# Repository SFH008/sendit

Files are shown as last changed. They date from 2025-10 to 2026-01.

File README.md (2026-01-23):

# SendIt — Open Hardware ADC Multitool

SendIt is an open-hardware, open-firmware controller designed as a multi use tool for handling various inputs with a focus on DIY marine usage.  It runs on the Yarrboard Framework and provides a clean web UI for configuration, and multiple different APIs for accessing your data.

Built on the **ESP32-S3**, SendIt has 8 channels of 16-bit ADC with 5 different types of configurable input circuits.  With this board, each channel can be individually configured to handle these types of inputs:

* **4-20ma Transducers/Senders:** sender between +VE and GND
* **Positive Switching:** 0-32v, voltage divider acts as pulldown when NC, switch between SIGNAL and +VE
* **Negative Switching:** 1k ohm, top half of voltage divider acts as pullup, switch between SIGNAL and GND
* **0-32v:** simple voltage divider, voltage wired to SIGNAL
* **0-10k ohm:** voltage divider, external resistor wired from SIGNAL to GND
* **0-5v:** simple voltage divider, voltage wired to SIGNAL
* **Thermistor:** 0-10k ohm, wired as normal
* **Raw/Passthrough:** no extra circuitry - wire your own custom circuit

# Hardware

## Controller Board

### Core capabilities:

- ESP32-S3 module with WiFi and USB-C  
- 12–30 V DC input with onboard power regulation  
- Can be powered by USB C or external power input
- 8 x 16-bit ADC channels with 5 selectable circuits
- Selectable sensor VCC voltage for each channel (3.3v, 5v, 24v, external power)
- 30mA resettable fuse on sensor VCC
- I²C expansion (QWIIC connector)
- Unused I/O broken out as 2.54mm pin headers

### Rev C Pinout

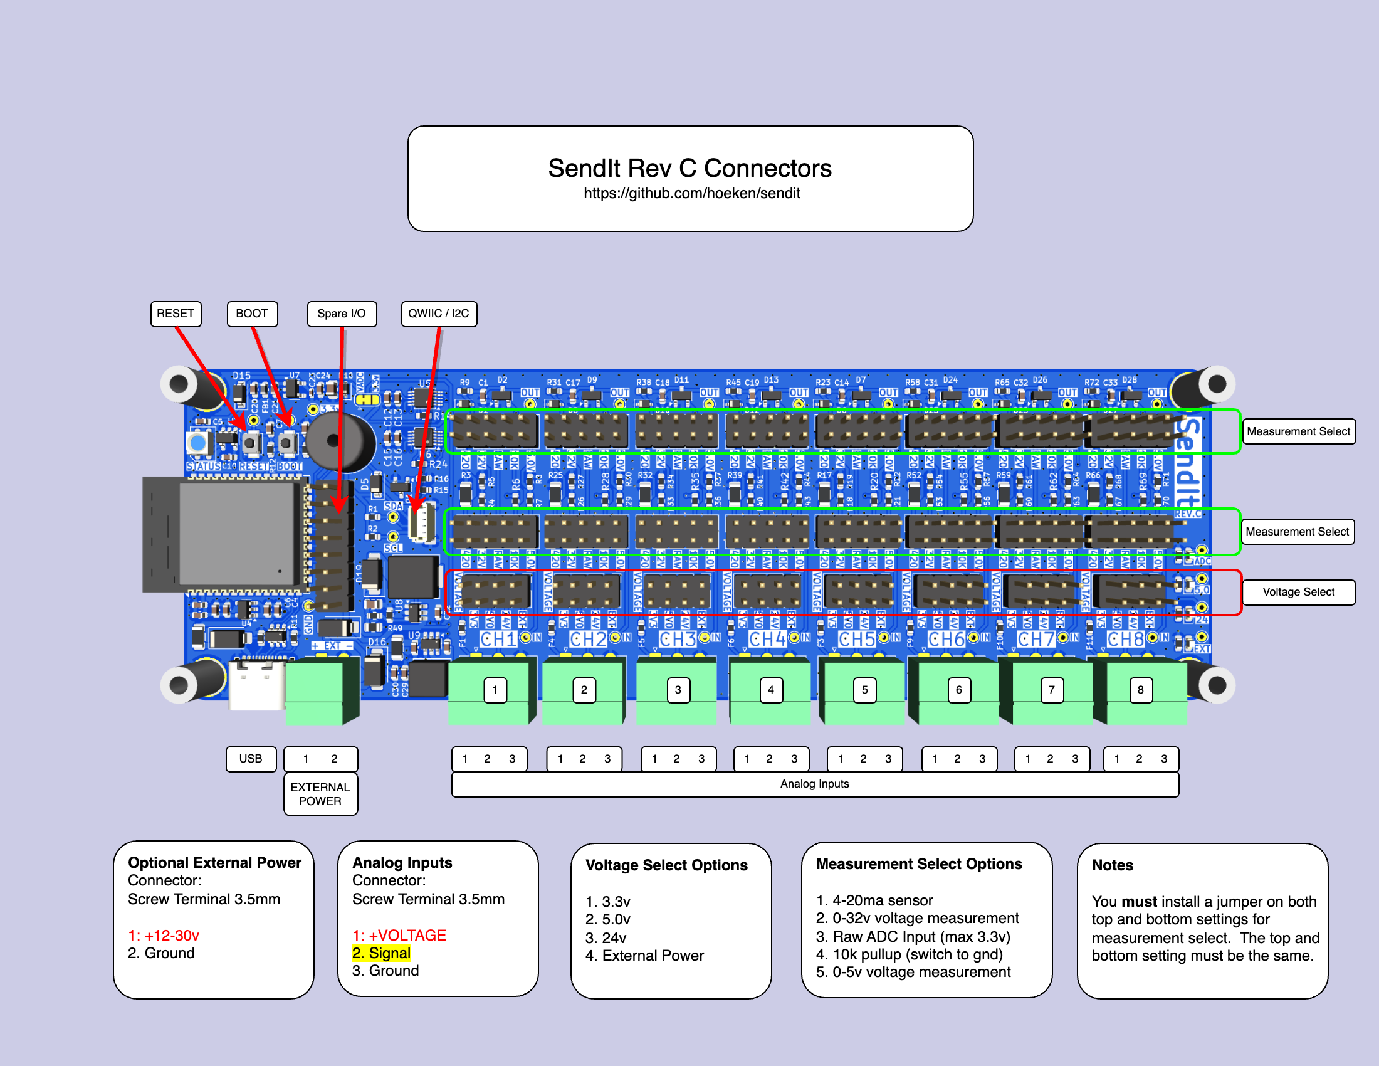
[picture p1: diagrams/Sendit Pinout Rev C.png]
SendIt Rev C Pinout


### ADC Input Channel

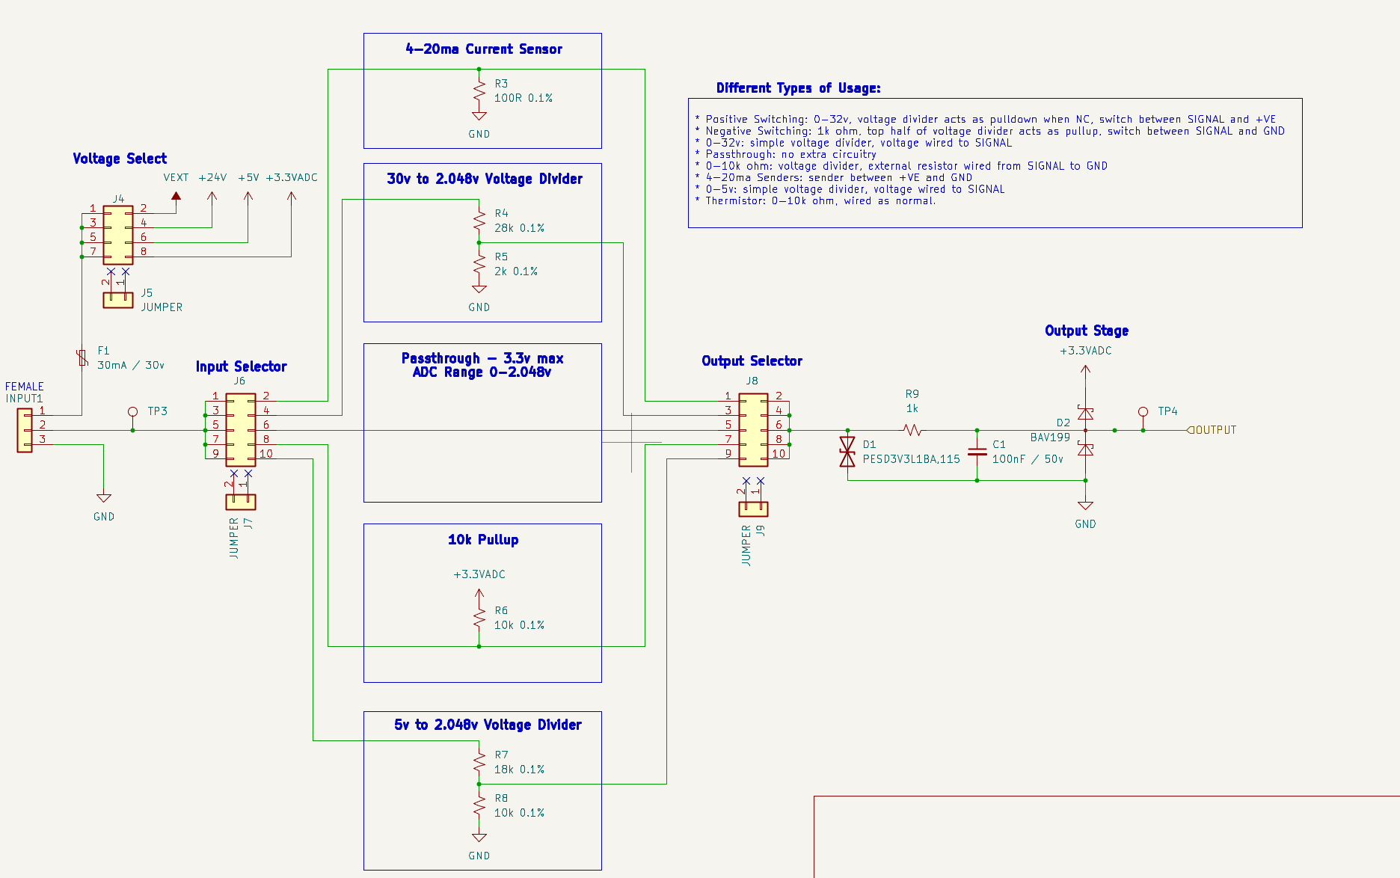
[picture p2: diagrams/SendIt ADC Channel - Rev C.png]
SendIt Rev C ADC Channel


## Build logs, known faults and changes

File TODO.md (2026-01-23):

# Rev D TODO

* lm74700 reverse polarity on VEXT
* remove pesd3.3v on adc line
* 1k -> 4.7k on the adc input line
* pull in the new esp32-s3 schematic w/ bigger ldo
* wrong p/n for leds - change to green
* 5v + 24v leds still way too bright - check resistor values and change.
* add more thermal gnd vias for regulators
* ideal diode ORing setup on 24v->5v output and USB 5v output
  * Wuxi Maxinmicro MX74610SS (external fet)
  * LM74700 (external fet, p/n re-use)
* usb 5v output -> ideal diode.
* bulk cap on 5v
* expansion header -> bottom and change to smt
* change to bigger / higher amperage chip for 5v to 24v
  * TI TPS55340 -> modern, internal, async -> easy peasy <winner>
  * TI TPS40211 -> modern, external, async kinda complicated
  * TI TPS43061 -> synchronous / more complicated
* change to bigger / higher amperage chip for 24v to 5v
  * DIODES AP64350 (3.5A)
  * DIODES AP64200 (2A)
* add bottom test points to important input / outputs
* update all p/ns per bom/ff

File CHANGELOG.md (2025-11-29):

# Changelog

## REV C

### 🔧 ADC & Analog Front-End
- Switched back to **ADS1115** ADC.
- Removed the **ADC VREF circuit** and added a **solder jumper** for VREF selection.
- Standardized all analog scaling to **2.048 V** reference (instead of 3.3 V).
- Added voltage dividers for **30 V** and **5 V** input ranges.
- Set **4–20 mA shunt resistor** to **100 Ω**.
- Added **pull-up resistors** on ADS1115 ALERT pin.

### ⚡ Power & Regulation
- Added a **buck converter** on the EXT port for **12/24 V → 5 V** to power the ESP32.
  - Includes a jumper to **enable/disable EXT-port power**.
  - EXT port may now be used as **power-only**, **reference-only**, or **both**.
- Added **3.3 V ↔ 5.0 V buffer** for WS2818 LED.
- Switched to **green LEDs** for power indication.
- Removed the **USB-to-serial** and **USB hub** for a simplified ESP32-S3 design.

### 🧩 Connectors & I/O
- Added **QWIIC header**.
- Moved pluggable terminal blocks **down 0.5 mm**.
- Removed jumper for EXT power selection.

### 🧪 Test Points
- Added test points for **3.3 V**, **5.0 V**, **24 V**, **GND**, **SDA**, **SCL**, and others.
- Standardized all test points to **1.5×0.7 mm**.

### 🔊 Piezo & Indicators
- Switched to **passive piezo** and added diode (**Huaneng QMB-09B-03**).

### 🧱 Mechanical & Layout
- Changed upper mounting holes to **SMTSO3080CTJ** hardware.
- Switched to **SMT boot/reset buttons**.
- Removed RTC **clock crystal**.
- Switched boost converter to **MT3608B** for 24 V generation.

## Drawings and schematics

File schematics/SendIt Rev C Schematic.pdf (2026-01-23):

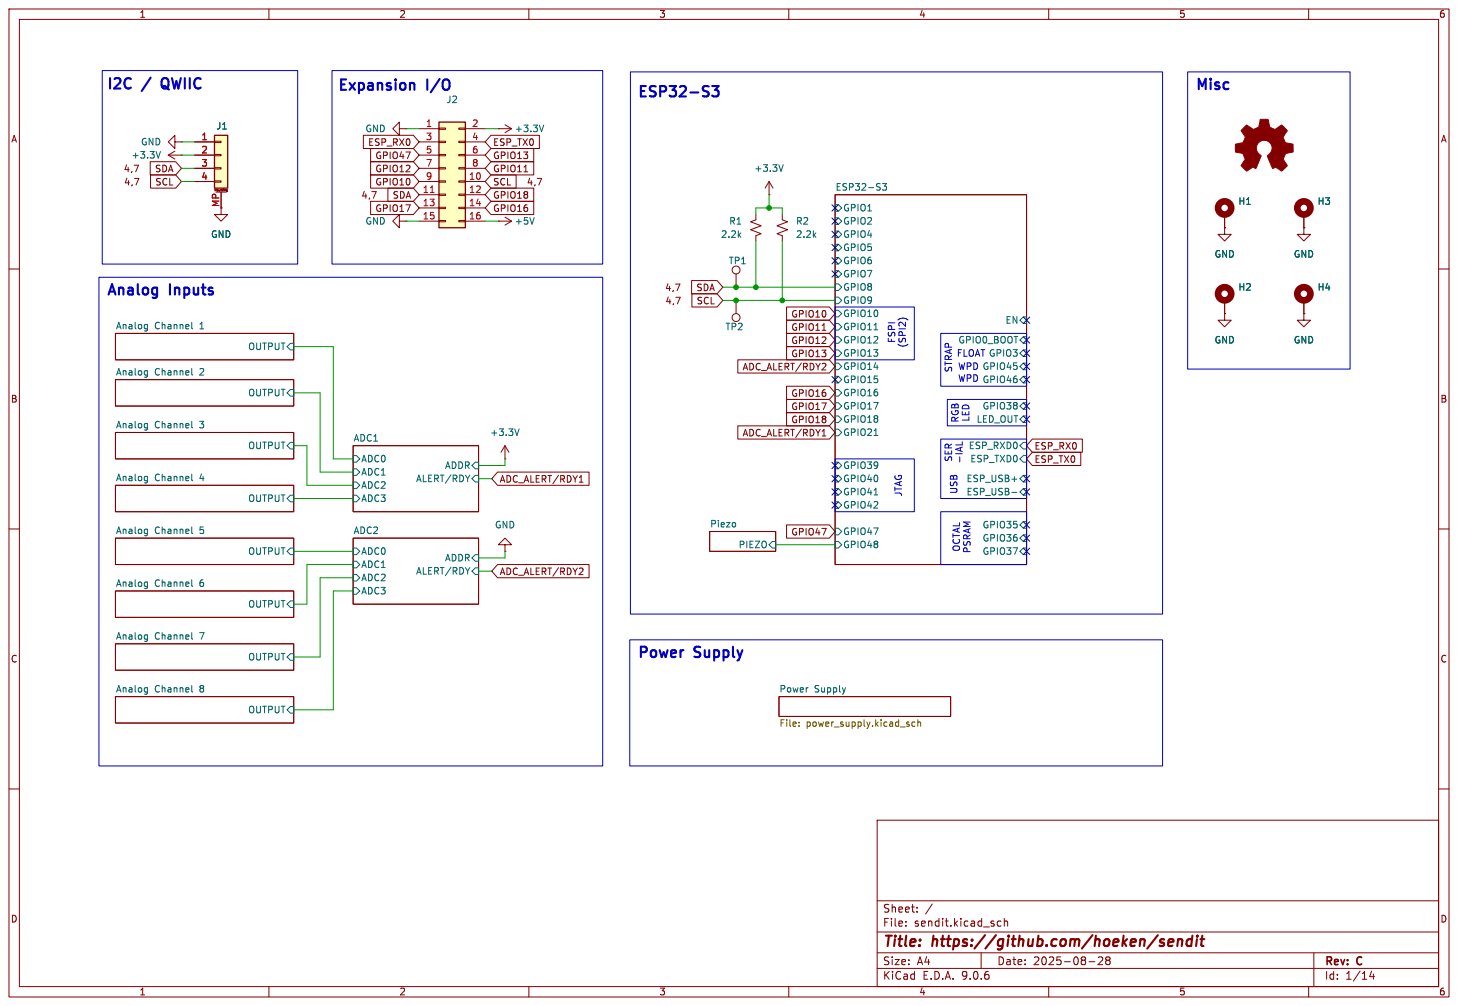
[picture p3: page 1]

Id: 1/14 Title: https://github.com/hoeken/sendit File: sendit.kicad_sch Sheet: /

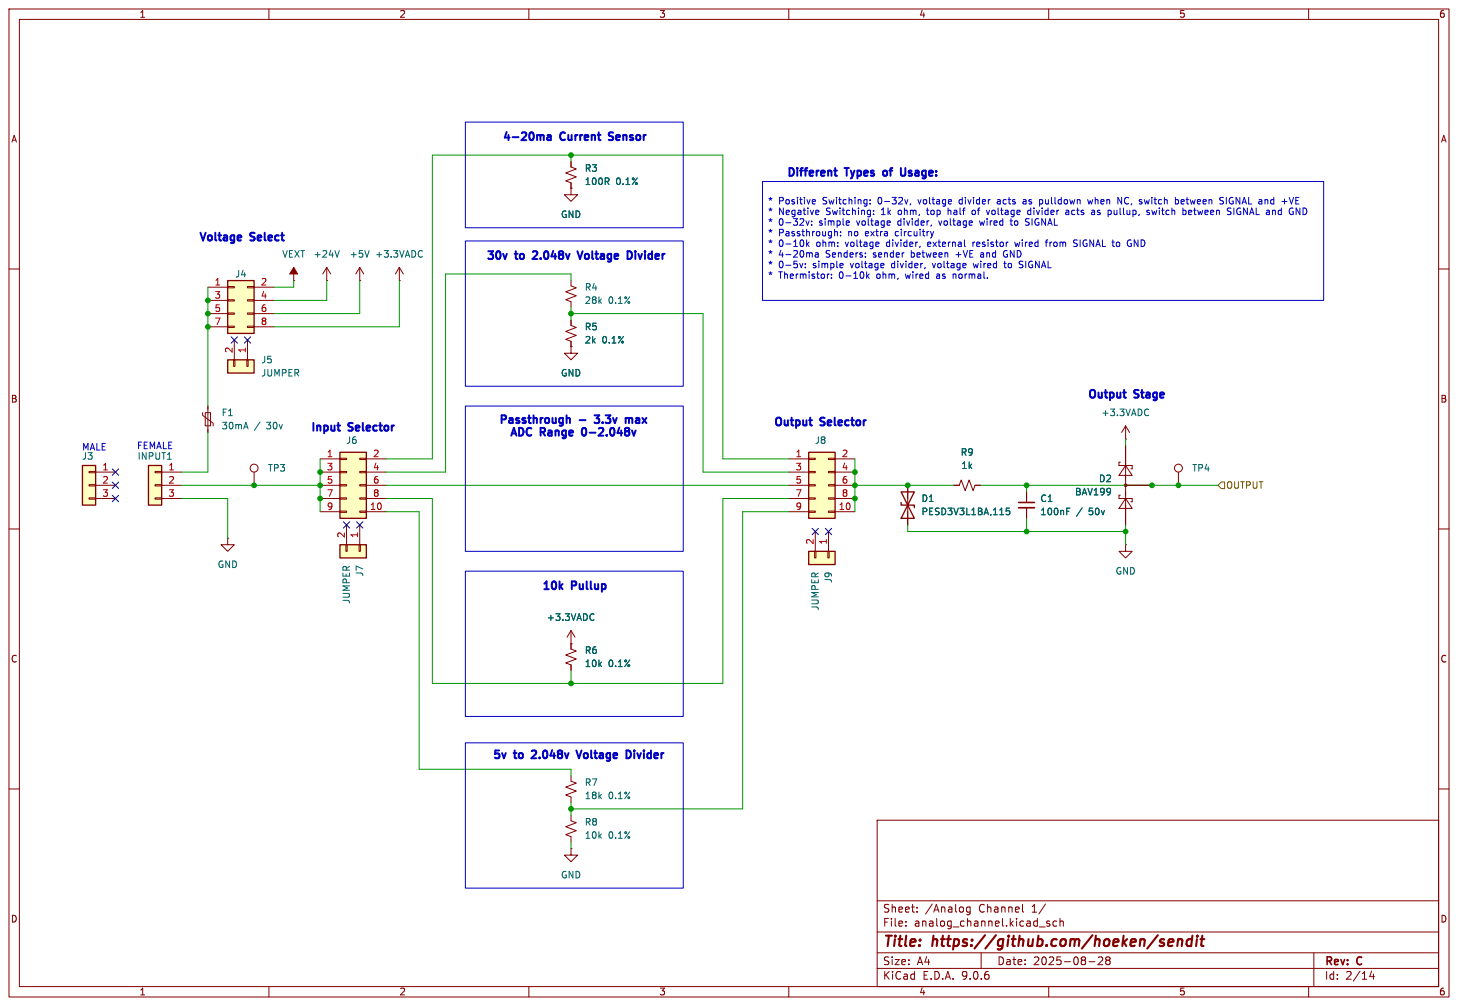
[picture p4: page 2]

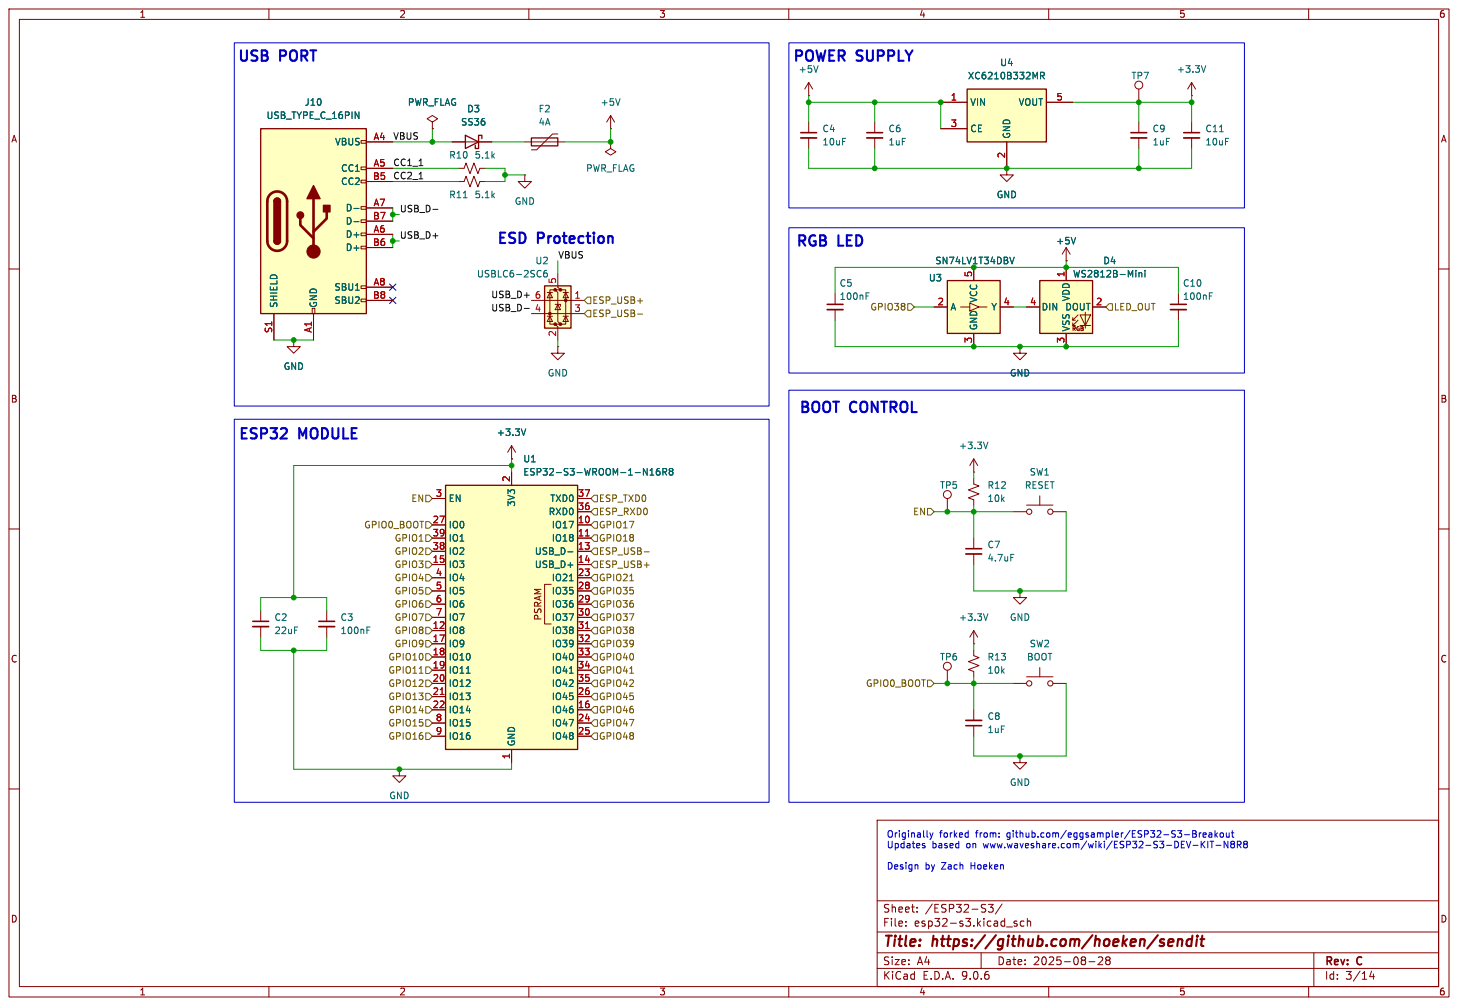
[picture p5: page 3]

Updates based on www.waveshare.com/wiki/ESP32-S3-DEV-KIT-N8R8 Design by Zach Hoeken RGB LED

Id: 3/14 Title: https://github.com/hoeken/sendit File: esp32-s3.kicad_sch Sheet: /ESP32-S3/

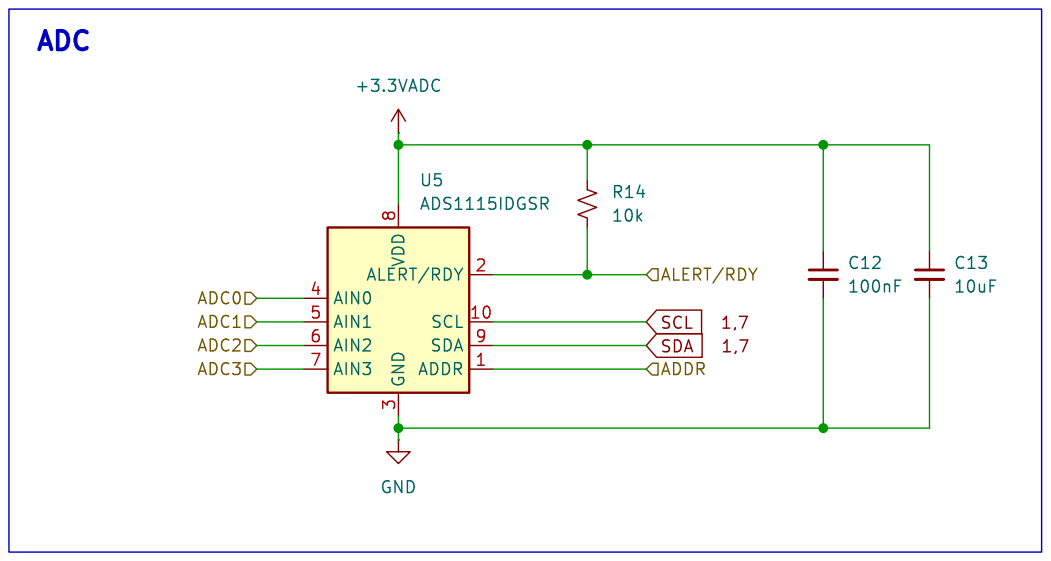
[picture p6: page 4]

3 ALERT/RDY 2 SCL 10 SDA 9 ADDR 1 U5ADS1115IDGSR

File: 1115_adc.kicad_sch Sheet: /ADC1/
Id: 4/14 Title: https://github.com/hoeken/brineomatic

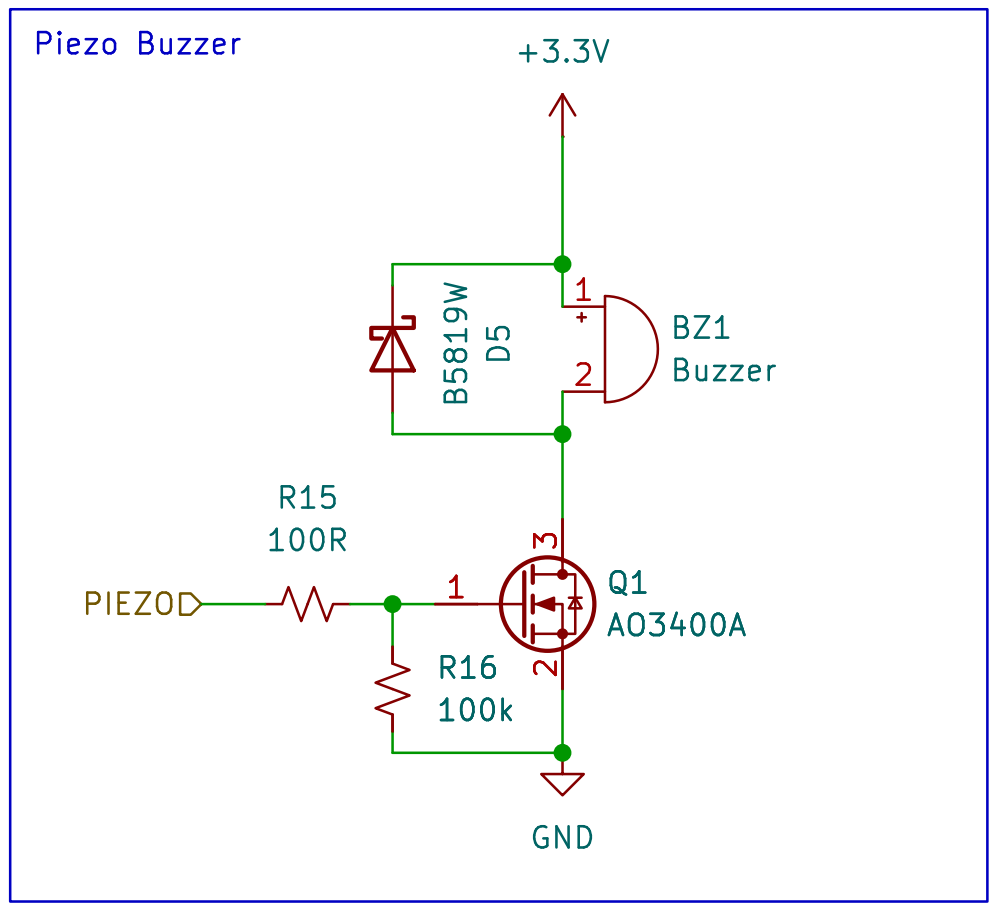
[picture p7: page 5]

Id: 5/14 Title: https://github.com/hoeken/sendit File: piezo.kicad_sch Sheet: /Piezo/ R16

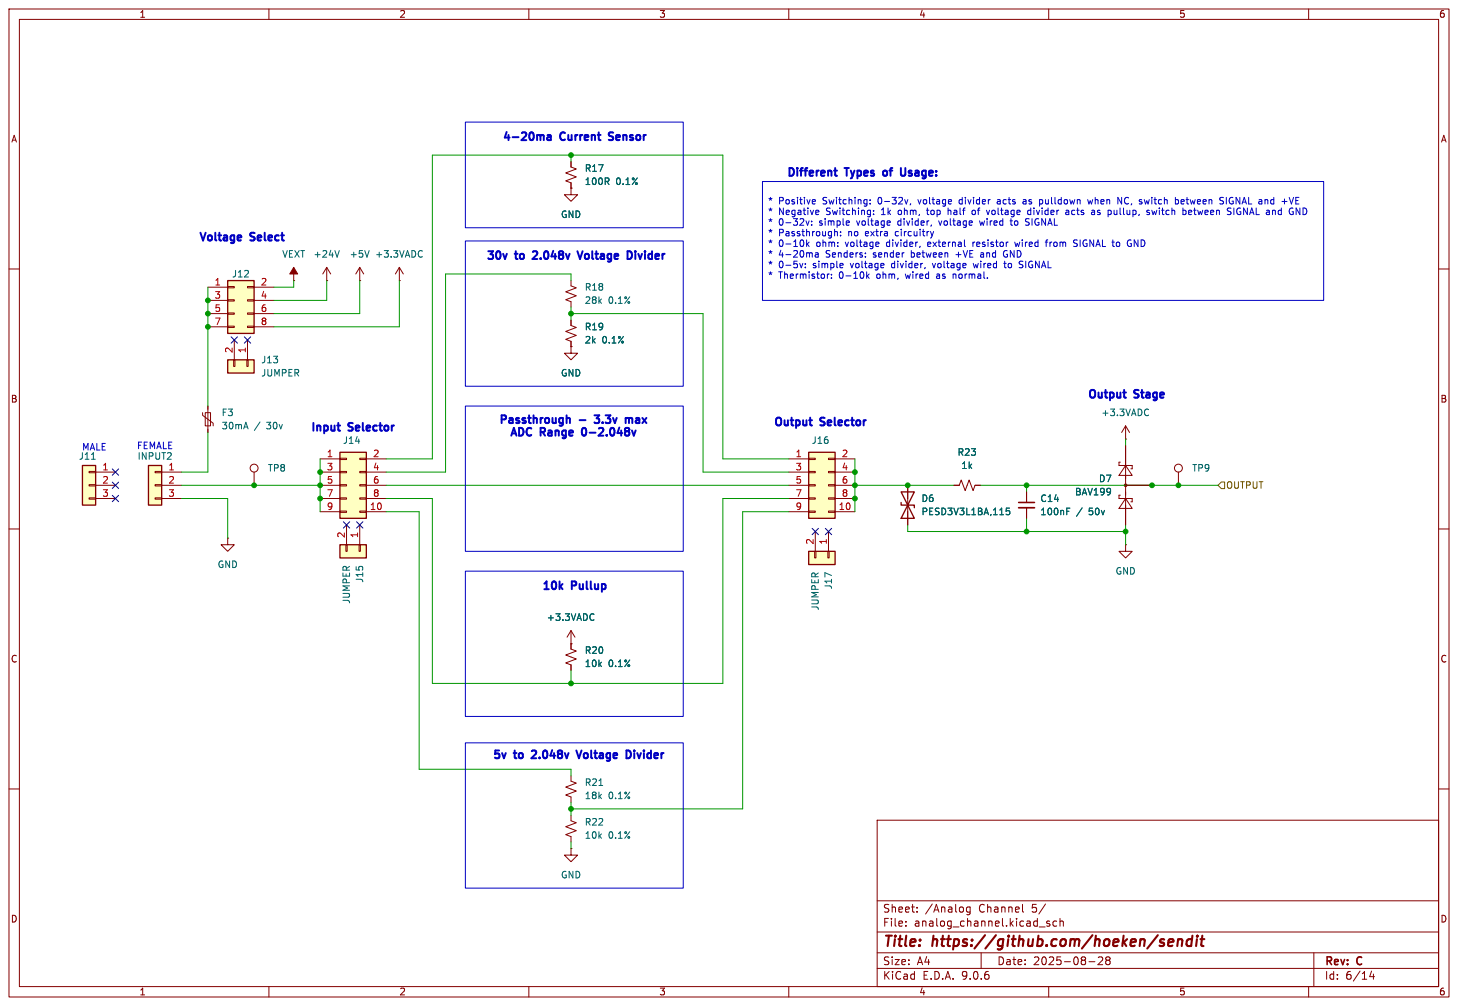
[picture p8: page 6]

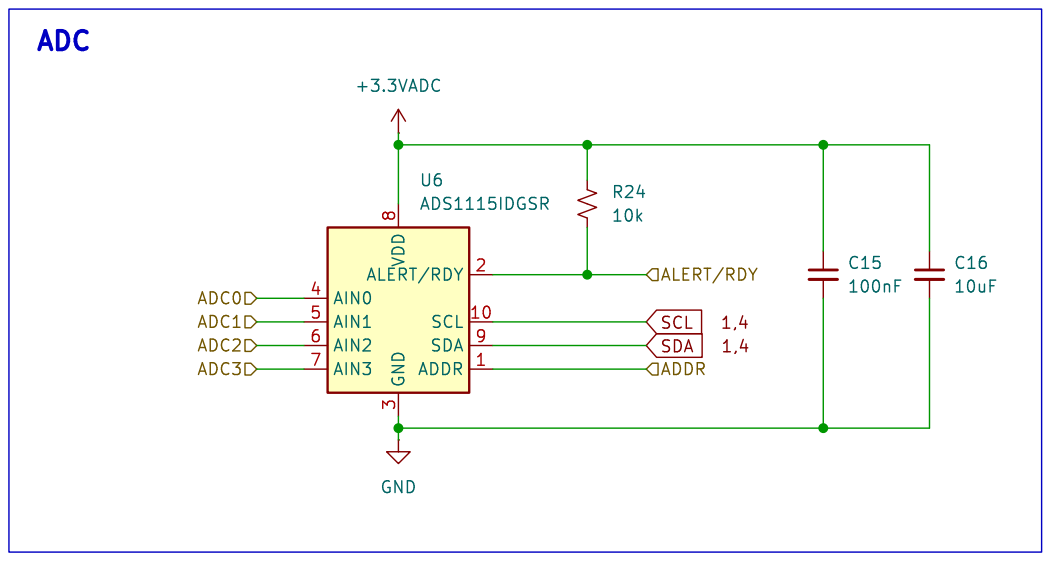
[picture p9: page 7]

3 ALERT/RDY 2 SCL 10 SDA 9 ADDR 1 U6ADS1115IDGSR

File: 1115_adc.kicad_sch Sheet: /ADC2/
Id: 7/14 Title: https://github.com/hoeken/brineomatic

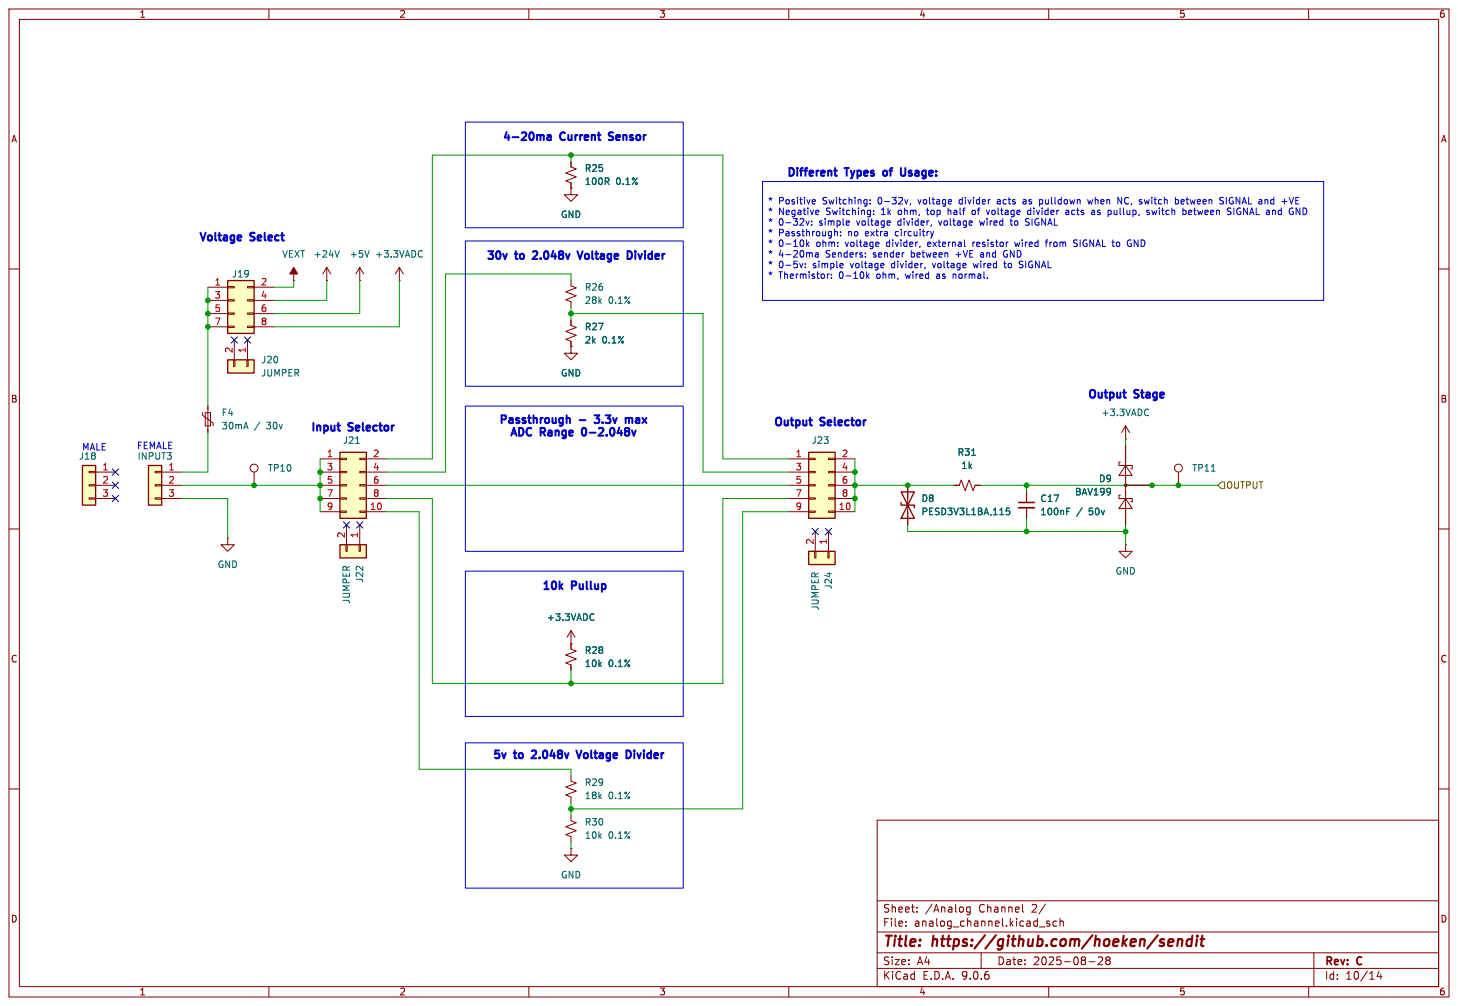
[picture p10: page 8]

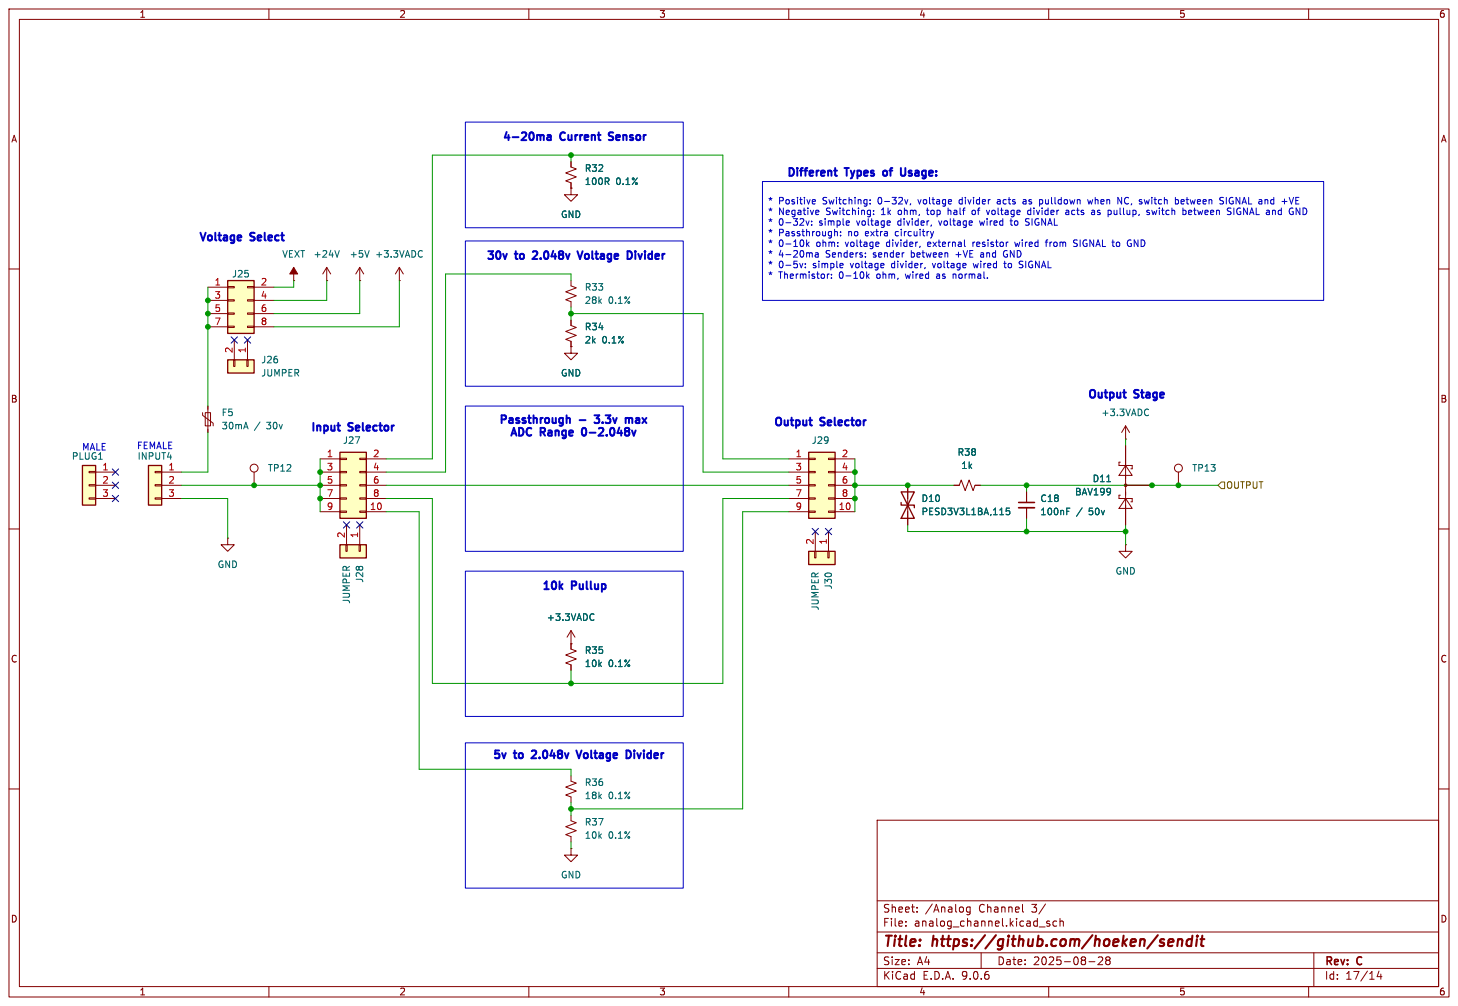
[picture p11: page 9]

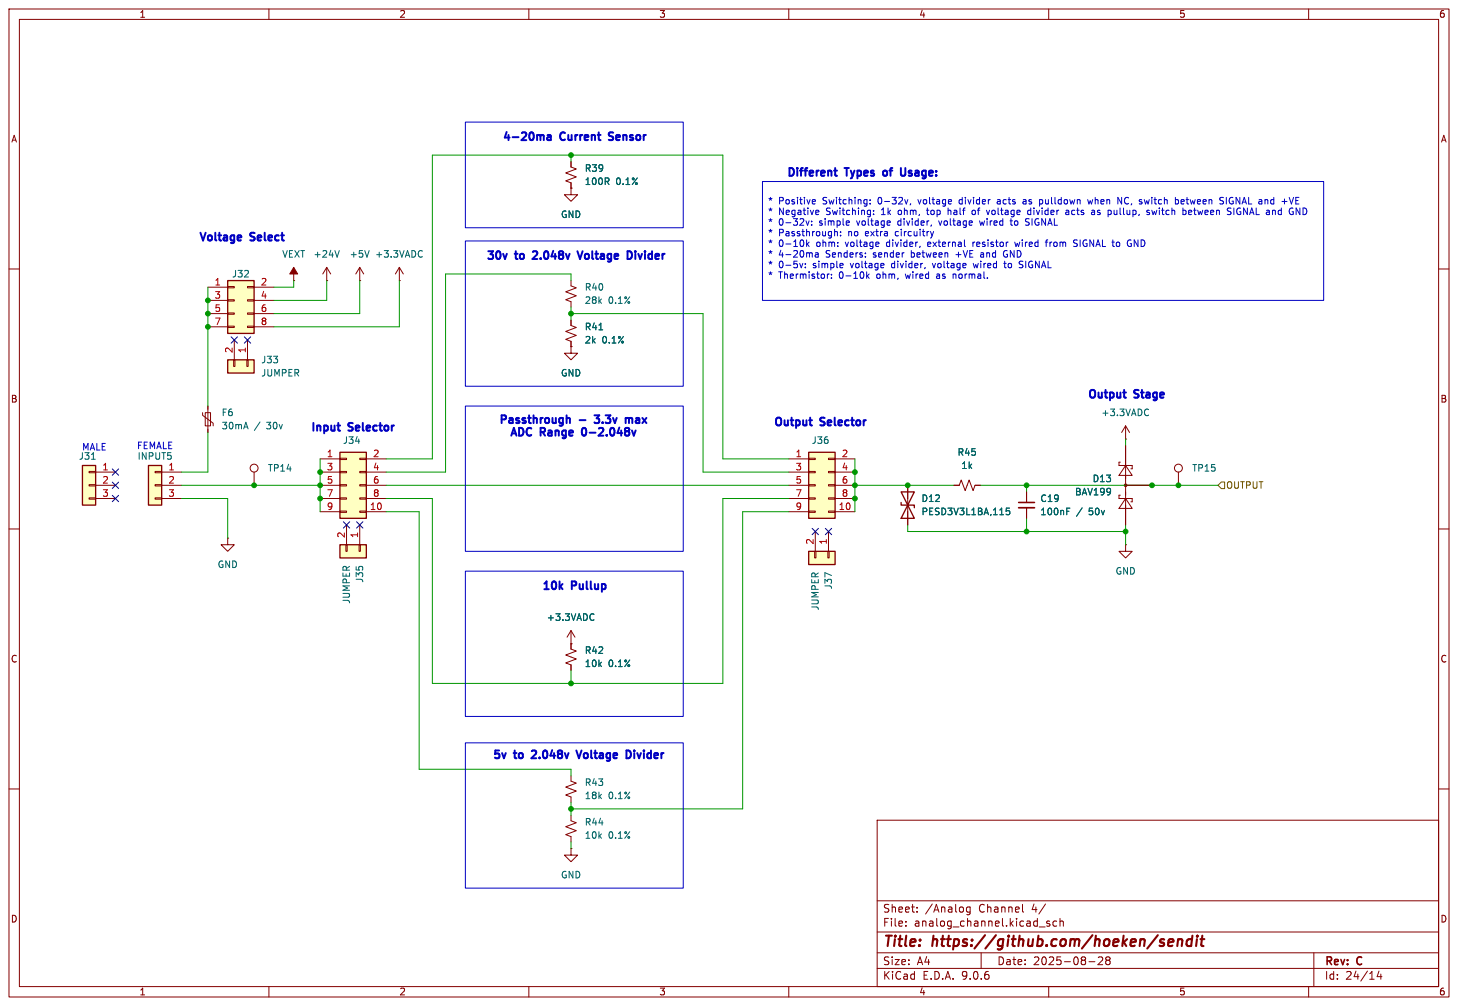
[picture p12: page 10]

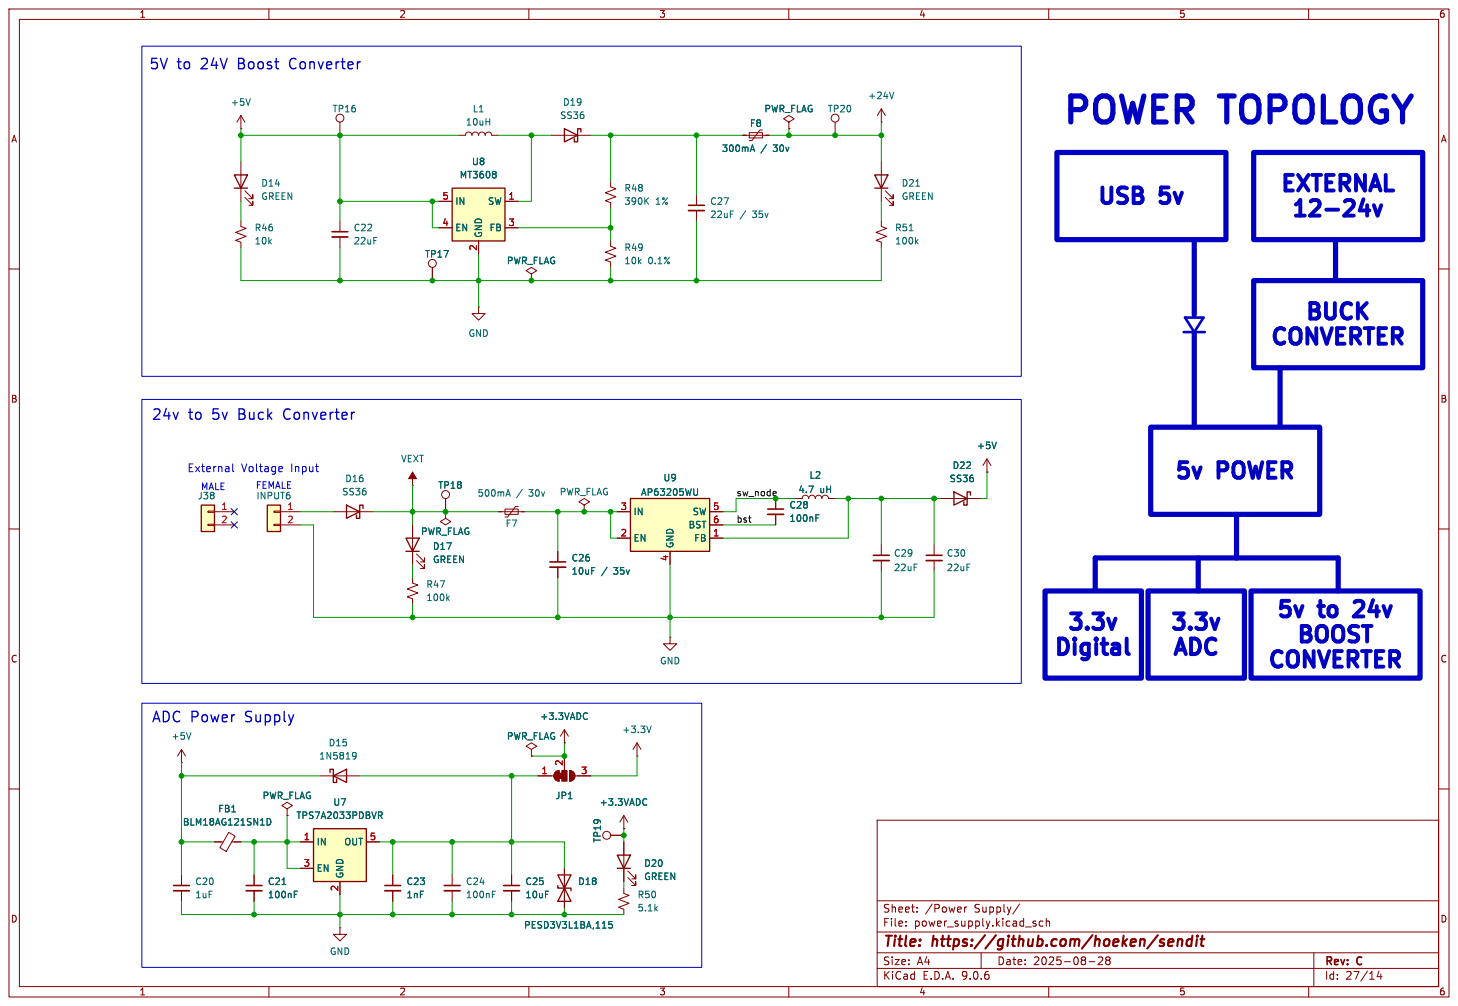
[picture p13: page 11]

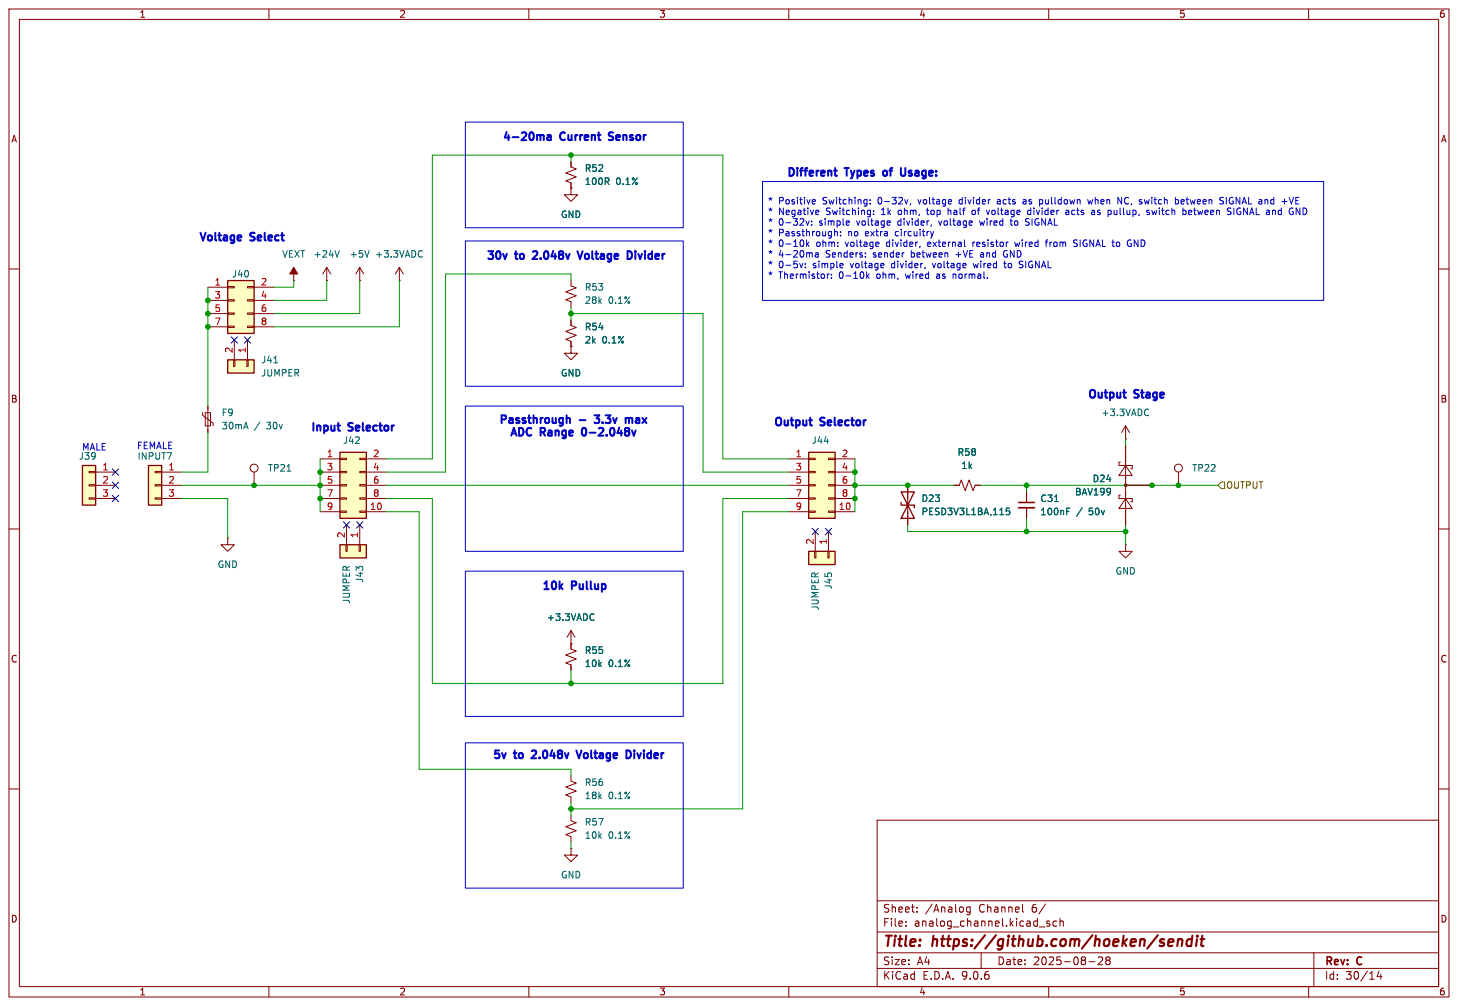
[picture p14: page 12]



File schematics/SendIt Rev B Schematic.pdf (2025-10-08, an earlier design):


Id: 1/13 Title: https://github.com/hoeken/sendit File: sendit.kicad_sch Sheet: / Power Supply File: power_supply.kicad_sch


3 3 | 4 4
5 5 | 6 6
7 7 | 8


3 3 | 4 4
5 5 | 6 6
7 7 | 8


3 3 | 4 4
5 5 | 6 6
7 7 | 8


3 3 | 4 4
5 5 | 6 6
7 7 | 8


3 3 | 4 4
5 5 | 6 6
7 7 | 8


3 3 | 4 4
5 5 | 6 6
7 7 | 8


3 3 | 4 4
5 5 | 6 6
7 7 | 8


3 3 | 4 4
5 5 | 6 6
7 7 | 8


Id: 4/13 Title: https://github.com/hoeken/sendit File: adc.kicad_sch Sheet: /ADC/ https://github.com/hoeken/frothfet C22


Id: 5/13 Title: https://github.com/hoeken/sendit File: piezo.kicad_sch Sheet: /Piezo/


1 TXD 4 RXD 5 ~{ACT} 10 ~{CTS} 15 ~{DSR} 14 ~{RI} 16 ~{DCD} 11 ~{DTR} 12 ~{RTS} 13 C18

1 TXD 4 RXD 5 ~{ACT} 10 ~{CTS} 15 ~{DSR} 14 ~{RI} 16 ~{DCD} 11 ~{DTR} 12 ~{RTS} 13 U5 CH343P

USB CHIPS POWER SAVER

Updates based on www.waveshare.com/wiki/ESP32-S3-DEV-KIT-N8R8 Design by Zach Hoeken


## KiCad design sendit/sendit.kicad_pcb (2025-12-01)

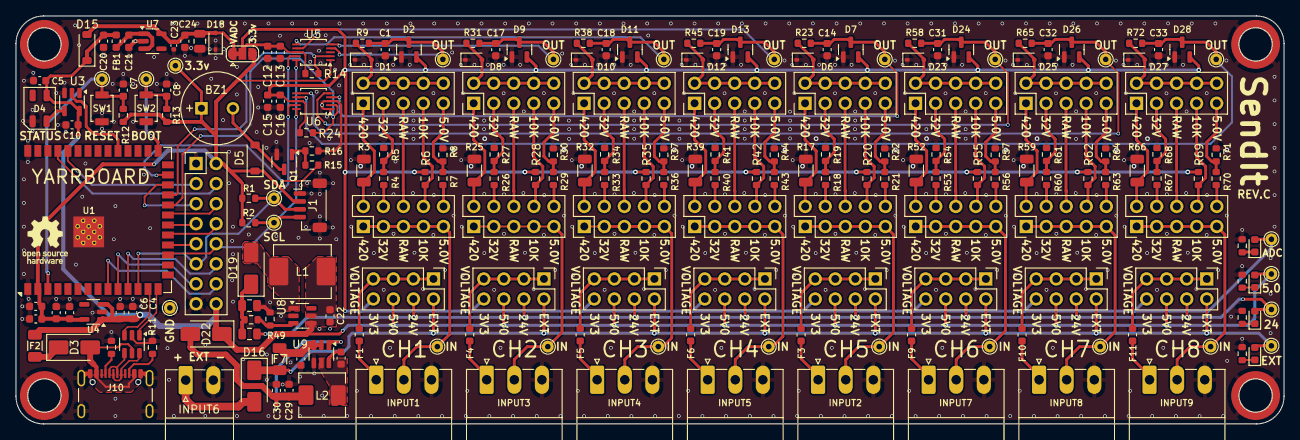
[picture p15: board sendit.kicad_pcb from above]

Board: 4 copper layers, 160.7 x 51.7 mm, 228 parts (0 on the bottom side), 145 nets.

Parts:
BZ1: Buzzer; MagneticBuzzer_QMB-09B-03
C1, C14, C17, C18, C19, C31, C32, C33: 100nF / 50v; C_0603_1608Metric
C2, C22, C29, C30: 22uF; C_0603_1608Metric
C3, C5, C10, C12, C15, C21, C24, C28: 100nF; C_0603_1608Metric
C4, C11, C13, C16: 10uF; C_0603_1608Metric
C6, C8, C9, C20: 1uF; C_0603_1608Metric
C7: 4.7uF; C_0603_1608Metric
C23: 1nF; C_0402_1005Metric
C25: 10uF; C_0805_2012Metric
C26: 10uF / 35v; C_0603_1608Metric
C27: 22uF / 35v; C_0805_2012Metric
D1, D6, D8, D10, D12, D18, D23, D25, D27: PESD3V3L1BA,115; D_SOD-323
D2, D7, D9, D11, D13, D24, D26, D28: BAV199; SOT-23
D3, D16, D19, D22: SS36; D_SMA
D4: WS2812B-Mini; LED_WS2812B-Mini_PLCC4_3.5x3.5mm
D5: B5819W; D_SOD-123
D14, D17, D20, D21: GREEN; LED_0603_1608Metric
D15: 1N5819; D_SOD-123
F1, F3, F4, F5, F6, F9, F10, F11: 30mA / 30v; Fuse_0603_1608Metric
F2: 4A; Fuse_1206_3216Metric
F7: 500mA / 30v; Fuse_1206_3216Metric
F8: 300mA / 30v; Fuse_0805_2012Metric
FB1: BLM18AG121SN1D; L_0603_1608Metric
H1, H2, H3, H4: MountingHole_Pad; SMTSO30XXX
INPUT1, INPUT2, INPUT3, INPUT4, INPUT5, INPUT7, INPUT8, INPUT9: Conn_01x03; PhoenixContact_MC_1,5_3-G-3.5_1x03_P3.50mm_Horizontal
INPUT6: Conn_01x02; PhoenixContact_MC_1,5_2-G-3.5_1x02_P3.50mm_Horizontal
J1: Conn_01x04_MountingPin; JST_SH_BM04B-SRSS-TB_1x04-1MP_P1.00mm_Vertical
J2: Conn_02x08_Odd_Even; PinHeader_2x08_P2.54mm_Vertical
J4, J12, J19, J25, J32, J40, J47, J54: PinHeader_2x04_P2.54mm_Vertical
J6, J8, J14, J16, J21, J23, J27, J29, J34, J36, J42, J44, J49, J51, J56, J58: Conn_02x05_Odd_Even; PinHeader_2x05_P2.54mm_Vertical
J10: USB_TYPE_C_16PIN; USB_C_Receptacle_GCT_USB4105-xx-A_16P_TopMnt_Horizontal
JP1: SolderJumper_3_Bridged12; SolderJumper-3_P1.3mm_Bridged12_RoundedPad1.0x1.5mm
L1: 10uH; L_TechFuse_SL0630
L2: 4.7 uH; L_Chilisin_BMRA00050530
LOGO1: Logo_Open_Hardware_Small; OSHW-Logo_5.7x6mm_SilkScreen
Q1: AO3400A; SOT-23
R1, R2: 2.2k; R_0603_1608Metric
R3, R17, R25, R32, R39, R52, R59, R66: 100R 0.1%; R_1206_3216Metric
R4, R18, R26, R33, R40, R53, R60, R67: 28k 0.1%; R_0603_1608Metric
R5, R19, R27, R34, R41, R54, R61, R68: 2k 0.1%; R_0603_1608Metric
R6, R8, R20, R22, R28, R30, R35, R37, R42, R44, R49, R55, R57, R62, R64, R69, R71: 10k 0.1%; R_0603_1608Metric
R7, R21, R29, R36, R43, R56, R63, R70: 18k 0.1%; R_0603_1608Metric
R9, R23, R31, R38, R45, R58, R65, R72: 1k; R_0603_1608Metric
R10, R11, R50: 5.1k; R_0603_1608Metric
R12, R13, R14, R24, R46: 10k; R_0603_1608Metric
R15: 100R; R_0603_1608Metric
R16, R47, R51: 100k; R_0603_1608Metric
R48: 390K 1%; R_0603_1608Metric
SW1: RESET; SW_SPST_B3U-1000P
SW2: BOOT; SW_SPST_B3U-1000P
TP1, TP2, TP5, TP6, TP7, TP16, TP17, TP18, TP19, TP20: TestPoint_THTPad_D1.5mm_Drill0.7mm
TP3, TP4, TP8, TP9, TP10, TP11, TP12, TP13, TP14, TP15, TP21, TP22, TP23, TP24, TP25, TP26: TestPoint; TestPoint_THTPad_D1.5mm_Drill0.7mm
U1: ESP32-S3-WROOM-1-N16R8; ESP32-S3-WROOM-1
U2: USBLC6-2SC6; SOT-23-6
U3: SN74LV1T34DBV; SOT-23-5
U4: XC6210B332MR; SOT-23-5
U5, U6: ADS1115IDGSR; TSSOP-10_3x3mm_P0.5mm
U7: TPS7A2033PDBVR; SOT-23-5
U8: MT3608; SOT-23-6
U9: AP63205WU; TSOT-23-6

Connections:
+3.3V: BZ1.1 (+), C2.1, C3.1, C9.1, C11.1, D5.1 (K), J1.2, J2.2, JP1.3 (B), R1.2, R2.2, R12.1, R13.2, TP7.1, U1.2 (3V3), U4.5 (VOUT), U5.1 (ADDR)
+3.3VADC: C12.1, C13.1, C15.1, C16.1, D2.2 (K), D7.2 (K), D9.2 (K), D11.2 (K), D13.2 (K), D20.2 (A), D24.2 (K), D26.2 (K), D28.2 (K), J4.8, J12.8, J19.8, J25.8, J32.8, J40.8, J47.8, J54.8, JP1.2 (C), R6.2, R14.1, R20.2, R24.1, R28.2, R35.2, R42.2, R55.2, R62.2, R69.2, TP19.1, U5.8 (VDD), U6.8 (VDD)
+5V: C4.1, C5.1, C6.1, C10.1, C20.1, C22.1, D4.1 (VDD), D14.2 (A), D15.1 (K), D22.1 (K), F2.2, FB1.1, J2.16, J4.6, J12.6, J19.6, J25.6, J32.6, J40.6, J47.6, J54.6, L1.1, TP16.1, U3.5 (VCC), U4.1 (VIN), U4.3 (CE), U8.4 (EN), U8.5 (IN)
+24V: D21.2 (A), F8.1, J4.4, J12.4, J19.4, J25.4, J32.4, J40.4, J47.4, J54.4, TP20.1
/ADC1/ADC0: C1.1, D2.3 (COM), R9.2, TP4.1, U5.4 (AIN0)
/ADC1/ADC1: C17.1, D9.3 (COM), R31.2, TP11.1, U5.5 (AIN1)
/ADC1/ADC2: C18.1, D11.3 (COM), R38.2, TP13.1, U5.6 (AIN2)
/ADC1/ADC3: C19.1, D13.3 (COM), R45.2, TP15.1, U5.7 (AIN3)
/ADC2/ADC0: C14.1, D7.3 (COM), R23.2, TP9.1, U6.4 (AIN0)
/ADC2/ADC1: C31.1, D24.3 (COM), R58.2, TP22.1, U6.5 (AIN1)
/ADC2/ADC2: C32.1, D26.3 (COM), R65.2, TP24.1, U6.6 (AIN2)
/ADC2/ADC3: C33.1, D28.3 (COM), R72.2, TP26.1, U6.7 (AIN3)
/ESP32-S3/CC1_1: J10.A5 (CC1), R10.1
/ESP32-S3/CC2_1: J10.B5 (CC2), R11.1
/ESP32-S3/EN: C7.1, R12.2, SW1.1, TP5.1, U1.3 (EN)
/ESP32-S3/ESP_USB+: U1.14 (USB_D+), U2.1 (I/O1)
/ESP32-S3/ESP_USB-: U1.13 (USB_D-), U2.3 (I/O2)
/ESP32-S3/GPIO0_BOOT: C8.2, R13.1, SW2.1, TP6.1, U1.27 (IO0)
/ESP32-S3/GPIO38: U1.31 (IO38), U3.2 (A)
/ESP32-S3/GPIO48: R15.2, U1.25 (IO48)
/ESP32-S3/USB_D+: J10.A6 (D+), J10.B6 (D+), U2.6 (I/O1)
/ESP32-S3/USB_D-: J10.A7 (D-), J10.B7 (D-), U2.4 (I/O2)
/ESP32-S3/VBUS: D3.2 (A), J10.A4 (VBUS), J10.A9 (VBUS), J10.B4 (VBUS), J10.B9 (VBUS), U2.5 (VBUS)
/Power Supply/bst: C28.2, U9.6 (BST)
/Power Supply/sw_node: C28.1, L2.1, U9.5 (SW)
ADC_ALERT/RDY1: R14.2, U1.23 (IO21), U5.2 (ALERT/RDY)
ADC_ALERT/RDY2: R24.2, U1.22 (IO14), U6.2 (ALERT/RDY)
ESP_RX0: J2.3, U1.36 (RXD0)
ESP_TX0: J2.4, U1.37 (TXD0)
GND: C1.2, C2.2, C3.2, C4.2, C5.2, C6.2, C7.2, C8.1, C9.2, C10.2, C11.2, C12.2, C13.2, C14.2, C15.2, C16.2, C17.2, C18.2, C19.2, C20.2, C21.2, C22.2, C23.2, C24.2, C25.2, C26.2, C27.2, C29.2, C30.2, C31.2, C32.2, C33.2, D1.1 (A1), D2.1 (A), D4.3 (VSS), D6.1 (A1), D7.1 (A), D8.1 (A1), D9.1 (A), D10.1 (A1), D11.1 (A), D12.1 (A1), D13.1 (A), D18.1 (A1), D23.1 (A1), D24.1 (A), D25.1 (A1), D26.1 (A), D27.1 (A1), D28.1 (A), H1.1, H2.1, H3.1, H4.1, INPUT1.3, INPUT2.3, INPUT3.3, INPUT4.3, INPUT5.3, INPUT6.2, INPUT7.3, INPUT8.3, INPUT9.3, J1.1, J1.MP (MountPin), J2.1, J2.15, J10.A1 (GND), J10.A12 (GND), J10.B1 (GND), J10.B12 (GND), J10.S1 (SHIELD), Q1.2 (S), R3.1, R5.1, R8.1, R10.2, R11.2, R16.2, R17.1, R19.1, R22.1, R25.1, R27.1, R30.1, R32.1, R34.1, R37.1, R39.1, R41.1, R44.1, R46.2, R47.2, R49.2, R50.2, R51.2, R52.1, R54.1, R57.1, R59.1, R61.1, R64.1, R66.1, R68.1, R71.1, SW1.2, SW2.2, TP17.1, U1.1 (GND), U1.40 (GND), U1.41 (GND), U2.2 (GND), U3.3 (GND), U4.2 (GND), U5.3 (GND), U6.1 (ADDR), U6.3 (GND), U7.2 (GND), U8.2 (GND), U9.4 (GND)
GPIO10: J2.9, U1.18 (IO10)
GPIO11: J2.8, U1.19 (IO11)
GPIO12: J2.7, U1.20 (IO12)
GPIO13: J2.6, U1.21 (IO13)
GPIO16: J2.14, U1.9 (IO16)
GPIO17: J2.13, U1.10 (IO17)
GPIO18: J2.12, U1.11 (IO18)
GPIO47: J2.5, U1.24 (IO47)
unnamed: BZ1.2 (-), D5.2 (A), Q1.3 (D)
unnamed: D1.2 (A2), J8.2, J8.4, J8.6, J8.8, J8.10, R9.1
unnamed: D3.1 (K), F2.1
unnamed: D4.4 (DIN), U3.4 (Y)
unnamed: D6.2 (A2), J16.2, J16.4, J16.6, J16.8, J16.10, R23.1
unnamed: D8.2 (A2), J23.2, J23.4, J23.6, J23.8, J23.10, R31.1
unnamed: D10.2 (A2), J29.2, J29.4, J29.6, J29.8, J29.10, R38.1
unnamed: D12.2 (A2), J36.2, J36.4, J36.6, J36.8, J36.10, R45.1
unnamed: D14.1 (K), R46.1
unnamed: C23.1, C24.1, C25.1, D15.2 (A), D18.2 (A2), JP1.1 (A), U7.5 (OUT)
unnamed: D16.2 (A), INPUT6.1
unnamed: D17.1 (K), R47.1
unnamed: D19.2 (A), L1.2, U8.1 (SW)
unnamed: C27.1, D19.1 (K), F8.2, R48.1
unnamed: D20.1 (K), R50.1
unnamed: D21.1 (K), R51.1
unnamed: C29.1, C30.1, D22.2 (A), L2.2, U9.1 (FB)
unnamed: D23.2 (A2), J44.2, J44.4, J44.6, J44.8, J44.10, R58.1
unnamed: D25.2 (A2), J51.2, J51.4, J51.6, J51.8, J51.10, R65.1
unnamed: D27.2 (A2), J58.2, J58.4, J58.6, J58.8, J58.10, R72.1
unnamed: F1.2, INPUT1.1
unnamed: INPUT1.2, J6.1, J6.3, J6.5, J6.7, J6.9, TP3.1
unnamed: F3.2, INPUT2.1
unnamed: INPUT2.2, J14.1, J14.3, J14.5, J14.7, J14.9, TP8.1
unnamed: F4.2, INPUT3.1
unnamed: INPUT3.2, J21.1, J21.3, J21.5, J21.7, J21.9, TP10.1
unnamed: F5.2, INPUT4.1
unnamed: INPUT4.2, J27.1, J27.3, J27.5, J27.7, J27.9, TP12.1
unnamed: F6.2, INPUT5.1
unnamed: INPUT5.2, J34.1, J34.3, J34.5, J34.7, J34.9, TP14.1
unnamed: F9.2, INPUT7.1
unnamed: INPUT7.2, J42.1, J42.3, J42.5, J42.7, J42.9, TP21.1
unnamed: F10.2, INPUT8.1
unnamed: INPUT8.2, J49.1, J49.3, J49.5, J49.7, J49.9, TP23.1
unnamed: F11.2, INPUT9.1
unnamed: INPUT9.2, J56.1, J56.3, J56.5, J56.7, J56.9, TP25.1
unnamed: F1.1, J4.1, J4.3, J4.5, J4.7
unnamed: J6.2, J8.1, R3.2
unnamed: J6.4, R4.2
unnamed: J6.6, J8.5
unnamed: J6.8, J8.7, R6.1
unnamed: J6.10, R7.2
unnamed: J8.3, R4.1, R5.2
unnamed: J8.9, R7.1, R8.2
unnamed: F3.1, J12.1, J12.3, J12.5, J12.7
unnamed: J14.2, J16.1, R17.2
unnamed: J14.4, R18.2
unnamed: J14.6, J16.5
unnamed: J14.8, J16.7, R20.1
unnamed: J14.10, R21.2
unnamed: J16.3, R18.1, R19.2
unnamed: J16.9, R21.1, R22.2
unnamed: F4.1, J19.1, J19.3, J19.5, J19.7
unnamed: J21.2, J23.1, R25.2
unnamed: J21.4, R26.2
unnamed: J21.6, J23.5
unnamed: J21.8, J23.7, R28.1
unnamed: J21.10, R29.2
unnamed: J23.3, R26.1, R27.2
unnamed: J23.9, R29.1, R30.2
unnamed: F5.1, J25.1, J25.3, J25.5, J25.7
unnamed: J27.2, J29.1, R32.2
unnamed: J27.4, R33.2
unnamed: J27.6, J29.5
unnamed: J27.8, J29.7, R35.1
unnamed: J27.10, R36.2
unnamed: J29.3, R33.1, R34.2
unnamed: J29.9, R36.1, R37.2
unnamed: F6.1, J32.1, J32.3, J32.5, J32.7
unnamed: J34.2, J36.1, R39.2
unnamed: J34.4, R40.2
unnamed: J34.6, J36.5
unnamed: J34.8, J36.7, R42.1
unnamed: J34.10, R43.2
unnamed: J36.3, R40.1, R41.2
unnamed: J36.9, R43.1, R44.2
unnamed: F9.1, J40.1, J40.3, J40.5, J40.7
unnamed: J42.2, J44.1, R52.2
unnamed: J42.4, R53.2
unnamed: J42.6, J44.5
unnamed: J42.8, J44.7, R55.1
unnamed: J42.10, R56.2
unnamed: J44.3, R53.1, R54.2
unnamed: J44.9, R56.1, R57.2
unnamed: F10.1, J47.1, J47.3, J47.5, J47.7
unnamed: J49.2, J51.1, R59.2
unnamed: J49.4, R60.2
unnamed: J49.6, J51.5
unnamed: J49.8, J51.7, R62.1
unnamed: J49.10, R63.2
unnamed: J51.3, R60.1, R61.2
unnamed: J51.9, R63.1, R64.2
unnamed: F11.1, J54.1, J54.3, J54.5, J54.7
unnamed: J56.2, J58.1, R66.2
unnamed: J56.4, R67.2
unnamed: J56.6, J58.5
unnamed: J56.8, J58.7, R69.1
unnamed: J56.10, R70.2
unnamed: J58.3, R67.1, R68.2
unnamed: J58.9, R70.1, R71.2
unnamed: Q1.1 (G), R15.1, R16.1
unnamed: C21.1, FB1.2, U7.1 (IN), U7.3 (EN)
unnamed: R48.2, R49.1, U8.3 (FB)
unnamed: C26.1, F7.2, U9.2 (EN), U9.3 (IN)
SCL: J1.4, J2.10, R2.1, TP2.1, U1.17 (IO9), U5.10 (SCL), U6.10 (SCL)
SDA: J1.3, J2.11, R1.1, TP1.1, U1.12 (IO8), U5.9 (SDA), U6.9 (SDA)
VEXT: D16.1 (K), D17.2 (A), F7.1, J4.2, J12.2, J19.2, J25.2, J32.2, J40.2, J47.2, J54.2, TP18.1

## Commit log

2025-03-17 big update on the potential design.
    [0-5v.kicad_sch, 10v.kicad_sch, 1115_adc.kicad_sch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]
2025-03-19 bigger update
    [0-5v.kicad_sch, 10v.kicad_sch, 1115_adc.kicad_sch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]
2025-03-19 cleaned up the dir.
    [0-5v.kicad_sch, 10v.kicad_sch, 420_sender.kicad_sch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]
2025-03-19 changed from mux to pin jumpers
    [analog_channel.kicad_sch, sendit.kicad_pcb, sendit.kicad_sch]
2025-07-30 layout work.
    [1115_adc.kicad_sch, analog_channel.kicad_sch, microsd.kicad_sch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]
2025-07-30 first pass layout finished.
    [sendit.kicad_pcb, sendit.kicad_sch]
2025-07-30 finished layout and routing
    [sendit.kicad_pcb, sendit.kicad_sch]
2025-08-07 updated footprints and lcsc numbers.
    [1115_adc.kicad_sch, analog_channel.kicad_sch, microsd.kicad_sch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]
2025-08-15 added fuses, 24v filters, and indicator leds.
    [analog_channel.kicad_sch, esp32 pin selection.ods, power_supply.kicad_sch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]
2025-08-15 test run of jlcpcb upload looks good.
    [1115_adc.kicad_sch, analog_channel.kicad_sch, esp32 pin selection.ods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]
2025-08-15 fully routed again.
    [analog_channel.kicad_sch, microsd.kicad_sch, sendit.kicad_pcb]
2025-08-15 passed erc and drc
    [sendit.kicad_pcb, sendit.kicad_sch]
2025-08-15 added shunts to the BOM
    [analog_channel.kicad_sch, esp32 pin selection.ods, sendit.kicad_pcb]
2025-08-15 switch to test points with drilled holes.
    [analog_channel.kicad_sch, esp32 pin selection.ods, sendit.kicad_pcb]
2025-08-15 added alert lines
    [1115_adc.kicad_sch, analog_channel.kicad_sch, esp32 pin selection.ods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]
2025-08-15 changed inductor on 24v circuit, cleaned up board a bit.
    [esp32 pin selection.ods, power_supply.kicad_sch, sendit.kicad_pcb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]
2025-08-15 Rev-A ready for production
    [power_supply.kicad_sch, sendit.kicad_pcb]
2025-08-15 Rev-A sent to production.
    [microsd.kicad_sch, sendit.kicad_pcb]
2025-10-01 big schematic rework for Rev B
    [adc.kicad_sch, analog_channel.kicad_sch, esp32-s3.kicad_sch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]
2025-10-02 ready for routing
    [power_supply.kicad_sch, sendit.kicad_pcb]
2025-10-02 brought over the latest esp32-s3 schematic
    [adc.kicad_sch, analog_channel.kicad_sch, esp32-s3.kicad_sch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]
2025-10-02 piezo resistor
    [piezo.kicad_sch, sendit.kicad_pcb, sendit.kicad_sch]
2025-10-02 first pass fully routed
    [power_supply.kicad_sch, sendit.kicad_sch]
2025-10-02 passing erc and drc
    [adc.kicad_sch, power_supply.kicad_sch, sendit.kicad_sch]
2025-10-03 silkscreen updated, looking good.
    [sendit.kicad_pcb, sendit.kicad_sch]
2025-10-03 ground plane / via stitching done
    [sendit.kicad_pcb]
2025-10-03 bom and placement looking good.
    [adc.kicad_sch, analog_channel.kicad_sch, esp32-s3.kicad_sch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]
2025-10-03 some final resistor value tweaking
    [analog_channel.kicad_sch, sendit.kicad_sch]
2025-10-04 cleaning up schematics a bit for design review
    [adc.kicad_sch, analog_channel.kicad_sch, esp32-s3.kicad_sch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]
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2025-10-08 added schematic and case
2025-11-07 started work on the rev c schematic
    [1115_adc.kicad_sch, analog_channel.kicad_sch, esp32-s3.kicad_sch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]
2025-11-08 more work on rev c board schematic
    [analog_channel.kicad_sch, esp32-s3.kicad_sch, piezo.kicad_sch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]
2025-11-08 most of the work on the schematic is done.
    [1115_adc.kicad_sch, analog_channel.kicad_sch, esp32-s3.kicad_sch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]
2025-11-10 more work towards rev c board.
    [1115_adc.kicad_sch, analog_channel.kicad_sch, esp32-s3.kicad_sch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]
2025-11-12 more rev c progress
    [power_supply.kicad_sch, sendit.kicad_pcb]
2025-11-12 power system work and layout
    [1115_adc.kicad_sch, analog_channel.kicad_sch, esp32-s3.kicad_sch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]
2025-11-13 big change removing the usb hub and serial chip.
    [1115_adc.kicad_sch, analog_channel.kicad_sch, esp32-s3.kicad_sch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]
2025-11-13 big routing push
    [analog_channel.kicad_sch, sendit.kicad_pcb, sendit.kicad_sch]
2025-11-13 first pass fully routed.
    [analog_channel.kicad_sch, esp32-s3.kicad_sch, piezo.kicad_sch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]
2025-11-13 finished extra pin selection + routing
    [sendit.kicad_pcb, sendit.kicad_sch]
2025-11-13 beefed up the 24v to 5v circuit
    [power_supply.kicad_sch, sendit.kicad_pcb]
2025-11-13 fixed erc errors
    [1115_adc.kicad_sch, power_supply.kicad_sch, sendit.kicad_sch]
2025-11-13 drc + silkscreen
    [sendit.kicad_pcb]
2025-11-13 a couple more silkscreen tweaks
    [sendit.kicad_pcb]
2025-11-13 via stitching and calculations
    [analog_channel.kicad_sch, calculations.ods, esp32-s3.kicad_sch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]
2025-11-14 double checked power supplies + gave esp32-s3 proper voltage/ground symbols
    [calculations.ods, esp32-s3.kicad_sch, power_supply.kicad_sch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]
2025-11-14 fixed spacer footprint
    [sendit.kicad_pcb, sendit.kicad_sch]
2025-11-14 all footprints have 3d models now
    [piezo.kicad_sch, sendit.kicad_pcb]
2025-11-14 moved the dc buck circuit away from the usb port.
    [esp32-s3.kicad_sch, power_supply.kicad_sch, sendit.kicad_pcb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]
2025-11-14 some bom work
    [analog_channel.kicad_sch, power_supply.kicad_sch, sendit.kicad_pcb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]
2025-11-15 added diode to prevent backfeed into 24v buck and beefed up 5v rail
    [1115_adc.kicad_sch, analog_channel.kicad_sch, esp32-s3.kicad_sch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]
2025-11-29 added pullup resistors to ads1115 alert line
    [1115_adc.kicad_sch, analog_channel.kicad_sch, piezo.kicad_sch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]
2025-11-29 updated changelog and production file tweak
    [power_supply.kicad_sch, sendit.kicad_pcb]
2025-12-01 fixed some silkscreen errors and added visas before submitting Rev C2 design
    [sendit.kicad_pcb]
2025-12-01 re-added reference designator for pullups
    [sendit.kicad_pcb]
